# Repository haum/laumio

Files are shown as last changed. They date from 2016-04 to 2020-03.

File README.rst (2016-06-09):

Laumio
######

Setup
=====

You need the Arduino IDE.

Install ESP8266 toolkit for Arduino
-----------------------------------

Instructions here : https://github.com/esp8266/Arduino

Install libraries
-----------------

- https://github.com/adafruit/Adafruit_NeoPixel
- https://github.com/bblanchon/ArduinoJson

Compiling
=========

Open sketch using Arduino
-------------------------

Open the laumio.ino sketch.

Select board
------------

Select the board in the board type to "WeMos D1 R2 & mini".

Flash
-----

You can now compile and flash the sketch to the board.

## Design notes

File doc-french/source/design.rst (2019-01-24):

Conception du Laumio
====================

Le Laumio est constitué d'une `lampe Ikea FADO`_ et d'une structure "maison" contrôlant 13 LEDs RGB.

Cette structure physique est elle-même constituée d'une partie mécanique supportant les lampes et du système électronique associé.

Partie mécanique
----------------

.. tip::

  Tous les fichiers de conception peuvent être récupérés `sur le dépôt Git`_.

La structure mécanique est composée d'un tronc central conçu pour se tenir sur la douille de l'ampoule. Celui-ci a été usiné grâce à une minifraiseuse et assemblé sans colle.

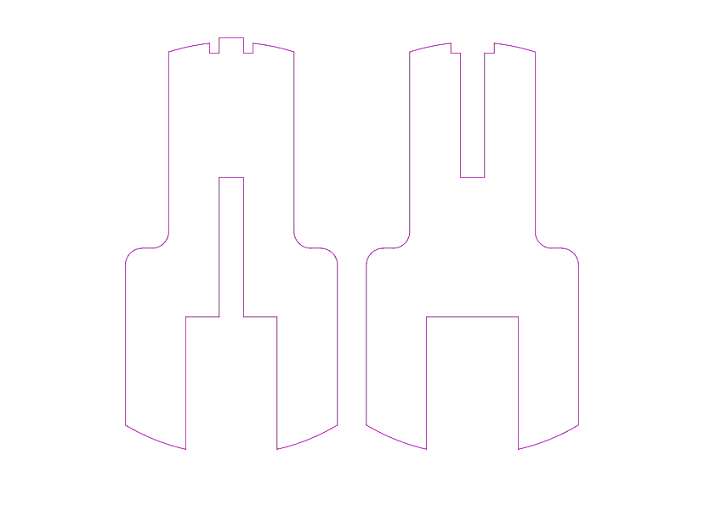
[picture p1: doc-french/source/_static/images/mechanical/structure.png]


Deux propositions ont ensuite été portées pour accueillir les LEDs en elles-mêmes.

La première proposition est basée sur des bras pliables, les LEDs étant collées à leurs extrémités. Les problèmes qui en découlent sont principalement la fragilité de la conception (notamment au niveau des soudures) et l'importante manipulation nécessaire pour insérer cet arbre dans le verre.

La seconde proposition est toujours à l'étude. Celle-ci utiliserait des bandes de plastique souple reliées en haut et en bas de la structure.

Système électronique
--------------------

Le système électronique est construit autour d'un `ESP Wemos d1 Mini`_ de de 13 LED WS2812. Afin de réutiliser le  Wemos dans d'autres projets, il a été décidé de créer un shield adapter pour y connecter le microcontrôleur.
Les fichiers de conception KiCAD design de ce shield peuvent être `téléchargés ici`_.

Le code utilisé dans l'ESP est aussi `présent sur le dépôt`_, merci de lire le fichier `README`_ pour être en mesure de compiler et de flasher le programme.

Une fois flashé et démarré, le Laumio va chercher à se connecter au réseau WiFi spécifié (voir
``wifi-config.h``) et attendre des instructions UDP ou HTTP.

Démarrage
---------

Au lancement, le Laumio clignote en violet puis démarre une animation de couleur rouge : il est en train de chercher le réseau WiFi spécifié et va tenter de s'y connecter.

Si la connexion est réussie, le Laumio lancera une animation Arc-en-ciel. Sinon, il s'illuminera en orage, signalant par-là que le mode *Access Point* est activé. Ce mode permettra à l'utilisateur de donner les informations nécessaires pour connecter l'appareil à un réseau WiFi valide.

.. _lampe Ikea FADO: http://www.ikea.com/us/en/catalog/products/70096377/
.. _ESP Wemos d1 Mini: http://www.wemos.cc/Products/d1_mini.html
.. _sur le dépôt Git: https://github.com/haum/laumio/tree/master/CAD
.. _téléchargés ici: https://github.com/haum/laumio/tree/master/kicad/wemos_d1mini_shield
.. _présent sur le dépôt: https://github.com/haum/laumio/tree/master/laumio
.. _README: https://github.com/haum/laumio/blob/master/README.rst

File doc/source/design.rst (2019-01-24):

Designing the Laumio
====================

Laumio is based on a `Ikea FADO lamp`_ and a homemade system bearing 13 RGB LED.

The physical system itself is composed of the mechanical part supporting the lamps and
the electronic board and system.

Mechanical Part
---------------

.. tip::

  All the design files can be found `on the Git repository`_.

The mechanical part is composed of a central structure designed to stand on the lightbulb
socket. It's is machined using a in-house CNC mill and dry-assembled.



Two different propositions were made to hold the LED themselves.

The first one is based on foldable arms with LED glued at the ends. The main issues are
both the fragility of the design and the effort needed to fit it in the glass.

The second one, still under study, is based on flexible plastic branches cruve from the to
to the bottom of the structure.

Electronic system
-----------------

The electronic system consist of a `ESP Wemos d1 Mini`_ and on 13 LED WS2812. To be able
to reuse the Wemos in other projects, it was decided to create a shield to dock it on. The
KiCAD design files for the shield itself can be `downloaded here`_.

The code running on the ESP is `given on the repo too`_, please follow the `README`_ to be
able to compile and flash it.

Once flashed and started, the Laumio will look for the specified Wifi network (see
``wifi-config.h``) and wait for UDP or HTTP instructions.

Booting
-------

At startup, the Laumio blinks in purple and then starts a red animation : it's looking for
the specified Wifi network and trying to connect.

If the connection is successful, the Laumio will show a rainbow animation, if not, it will
light up in orange, indicating the *Access Point* mode was started. This mode will allow
one to specify the correct information to connect to a Wifi network.

.. _Ikea FADO lamp: http://www.ikea.com/us/en/catalog/products/70096377/
.. _ESP Wemos d1 Mini: http://www.wemos.cc/Products/d1_mini.html
.. _on the Git repository: https://github.com/haum/laumio/tree/master/CAD
.. _downloaded here: https://github.com/haum/laumio/tree/master/kicad/wemos_d1mini_shield
.. _given on the repo too: https://github.com/haum/laumio/tree/master/laumio
.. _README: https://github.com/haum/laumio/blob/master/README.rst

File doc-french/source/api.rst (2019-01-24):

Anatomie du Laumio's et and commandes en valeurs hexadécimales
==============================================================

Le laumio peut être commandé via une API UDP minimale utilisant des commandes
simples en hexadécimal envoyées sur le **port 6969**, via une interface REST ou
à travers MQTT.

Quatre types de sous-ensembles sont utilisables pour commander les LEDs du
Laumio : le pixel (une seule led), l'anneau, la colonne et le Laumio dans son
intégralité. Il est aussi possible de lancer quelques animations plus spécifiques.

Les LEDs sont disposées en 4 branches de trois LEDs, en plus d'une à son sommet.
Celles-ci sont toutes numérotées de 0 à 12 depuis le bas d'une des branches vers
sa cîme, évitant l'unique led du sommet, descendant ensuite de l'autre côté de
la structure, et enfin remontant du bas d'une des deux branches restantes pour
atteindre le bas de la dernière (la LED de sommet étant cette fois-ci reliée
entre les deux branches).

Les anneaux correspondant quant à eux à une ligne horizontale de LEDs. Il y en a
trois numérotées de 0  à 2, de bas en haut.

Enfin, dans le cas des colonnes, celles-ci se rapportent aux quatre branches de
LEDs, bien entendu sans la LED du sommet.

API UDP minimale
----------------

Commande pixel par pixel
************************

La commande est ``0x00``. Les données à envoyer sont d'abord l'ID du pixel considéré et les trois octets de la couleur (RGB) choisie::

  0x00 PixelID R G B

Commande anneau par anneau
**************************

La commande est ``0x01``. Il faut d'abord spécifier l'ID de l'anneau (``0x00``, ``0x01`` or ``0x02``) puis préciser les trois octets de couleur::

  0x01 RingID R G B

Commande colonne par colonne
****************************

La commande est ``0x02``. Ici, il faut indiquer l'ID de la colonne (``0x00``, ``0x01``, ``0x02`` or ``0x03``) puis les trois octets de couleur::

  0x02 ColumnID R G B

Remplissage intégral
********************

La commande est ``0xff``, il suffit ensuite de specifier la couleur RGB::

  0xff R G B

Animations
**********

Les animations prédéfinies sont encore en développement mais deux d'entre elles ont déjà implémentées dans le Laumio.

Remplissage progressif
~~~~~~~~~~~~~~~~~~~~~~

L'animation de Remplissage progressif ("color wipe") change passe le Laumio intégralement dans une seule couleur, mais LED après LED. Elle prend deux paramètres, que sont les trois octets de la nouvelle couleur et l'intervalle de temps entre de deux LEDs en millisecondes::

  0x0b R G B Delay

Arc-en-ciel
~~~~~~~~~~~

L'animation Arc-en-ciel ("rainbow") ne prend pas de paramètres. En l'occurence, c'est celle utilisée par le Laumio quand celui-ci réussit à se connecter à un réseau WiFi::

  0x0a

API REST
--------

L'API REST peut être appelée en envoyant des données sur le chemin ``/api/``.

Statut
******

Le statut du Laumio peut être obtenu en utilisant un endpoint de l'``/api/``::

  GET http://<laumio_ip>/api/

La réponse reçue et de la forme suivante :

.. code-block:: javascript

  {"hostname":"laumio","version":"devel"}

Commandes
*********

Le Laumio peut être controllé à travers un simple requête POST avec une donnée
JSON jointe. Voir l'API JSON pour les détails du contenu de ces JSON.

En cas de succès :

.. code-block:: javascript

  {"hostname":"laumio","status":"Success"}

En cas d'erreur :

.. code-block:: javascript

  {"hostname":"laumio","status":"Invalid Request","massage":"Unable to parse JSON"}

API MQTT
--------

Si le Laumio a pu se connecter au broker, il peut être contrôlé à travers MQTT.

Status de connexion
********************

A la connexion le laumio publie sur le topic ``laumio/<name>/status`` son status de connexion,
Si le laumio se trouve hors ligne ce topic publiera un status offline

Annonce
*******

À la connexion, il publie son nom sur le topic ``laumio/status/advertise``.

Ce même message est envoyé quand il reçoit une commande ``discover``.

Commandes
*********

La commande est choisie en fonction du topic : ``laumio/all/<cmd>`` ou ``laumio/<name>/<cmd>``
selon que vous voulez l'envoyer à tous les clients connectés ou à un en particulier.

set_pixel
~~~~~~~~~

Change la couleur d'une led.

Les 4 octets du message sont le numéro de la led suivi des composantes rouge, vert, bleu de la couleur (0 à 255)

set_ring
~~~~~~~~~

Change la couleur d'un anneau.

Les 4 octets du message sont le numéro de l'anneau suivi des composantes rouge, vert, bleu de la couleur (0 à 255)

set_column
~~~~~~~~~~

Change la couleur d'une colonne.

Les 4 octets du message sont le numéro de la colonne suivi des composantes rouge, vert, bleu de la couleur (0 à 255)

color_wipe
~~~~~~~~~~

Démarre l'animation de remplissage progressif avec une couleur et une durée.

Les 4 octets du message sont les composantes rouge, vert, bleu de la couleur (0 à 255) suivies de la durée.

animate_rainbow
~~~~~~~~~~~~~~~

Démarre l'animation arc-en-ciel.

Le contenu du message est ignoré.

fill
~~~~

Change la couleur de toutes les leds.

Les 3 octets du message sont les composantes rouge, vert, bleu de la couleur (0 à 255)

json
~~~~

Envoie des commandes JSON via l'API JSON.

discover
~~~~~~~~

Renvoie un message sur le topic ``laumio/status/advertise`` contenant son nom.

API JSON
--------

Cette API ne peut pas être utilisée seule. Elle est accédée soit par la commande
``json`` de l'interface MQTT ou par l'API REST.

Commandes
*********

set_pixel
~~~~~~~~~

Change la couleur d'une led.

.. code-block:: javascript

  {
    'command': 'set_pixel',
    'led': PixelID,
    'rgb': [R, G, B]
  }

set_ring
~~~~~~~~~

Change la couleur d'un anneau.

.. code-block:: javascript

  {
    'command': 'set_ring',
    'ring': RingID,
    'rgb': [R, G, B]
  }

set_column
~~~~~~~~~~

Change la couleur d'une colonne.

.. code-block:: javascript

  {
    'command': 'set_column',
    'column': ColumnID,
    'rgb': [R, G, B]
  }

color_wipe
~~~~~~~~~~

Démarre l'animation de remplissage progressif avec une couleur et une durée.

.. code-block:: javascript

  {
    'command': 'color_wipe',
    'duration': Duration,
    'rgb': [R, G, B]
  }

animate_rainbow
~~~~~~~~~~~~~~~

Démarre l'animation arc-en-ciel.

.. code-block:: javascript

  {
    'command': 'animate_rainbow',
  }

fill
~~~~

Change la couleur de toutes les leds.

.. code-block:: javascript

  {
    'command': 'fill',
    'rgb': [R, G, B]
  }

Commandes multiples
*******************

Quelques commandes peuvent être chaînées dans un même appel lorsqu'elles
sont regroupées dans un tableau nommé ``commands``, mais notez que la
taille du JSON est quelque peu limitée.

.. code-block:: javascript

  {
    'commands': [
      {
        'command': 'set_column',
        'column': 0,
        'rgb': [255, 0, 0]
      },
      {
        'command': 'set_column',
        'column': 2,
        'rgb': [0, 0, 255]
      }
    ]
  }

Commande pixel par pixel (ancienne API)
***************************************

.. code-block:: javascript

  {
    'led': PixelID,
    'rgb': [R, G, B]
  }

Remplissage intégral (ancienne API)
***********************************

.. code-block:: javascript

  {
    'led': 255,
    'rgb': [R, G, B]
  }

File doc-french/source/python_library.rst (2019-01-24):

Librairie Python
================

La classe ``Laumio`` est construite comme une encapsulation des commandes minimales présentées dans la `page de l'API`_.

.. py:class:: Laumio

  .. py:method:: __init__(ip)

    Constructeur pour contrôler un Laumio répondant à l'adresse IP *ip*.

  .. py:method:: wipeOut()

    Eteint toutes les LEDs.

    *En réalité juste un alias pour :py:method:`fillColor`*.

  .. py:method:: fillColor(r, g, b)

    Remplit toutes les LEDs du Laumio avec la couleur (*r*, *g*, *b*).

  .. py:method:: fillRing(ringid, r, g, b)

    Remplit un anneau d'une seule couleur. *ringid* est dans l'intervalle 0~3 et *r*, *g*, *b* précisent la couleur.
    La LED du sommet n'est pas commandable ici.

  .. py:method:: fillColumn(colmunid, r, g, b)

    Remplit une colonne d'une seule couleur. *columnid* est dans l'intervalle 0~4 et *r*, *g*, *b* précisentla couleur.
    La LED du sommet n'est pas incluse dans les colonnes.

  .. py:method:: setPixelColor(pixel, r, g, b)

    Passe un pixel *pixel* (0~12) à la couleur (*r*, *g*, *b*) demandée.

  .. py:method:: colorWipe(r, g, b, delay)

    Lance une animation de remplissage progressif avec la color (*r*, *g*, *b*) et un intervalle de temps *delay* entre deux LEDs.

  .. py:method:: rainbow()

    Lance une animation arc-en-ciel.

  .. py:method:: status()

    Return the JSON **string** for the Laumio's status

  .. py:method:: _send(payload)

    Conventionnaly private, this method is used to transmit a raw ``bytearray`` payload to
    a Laumio. It can be used to trigger custom animations.

.. _page de l'API: /api.html

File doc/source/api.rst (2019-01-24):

Laumio's anatomy and HEX commands
=================================

The Laumio can be controlled using the bare-UDP API using simple HEX commands sent on the
**port 6969**, using REST API or through MQTT.

Four different features can be set : the pixel, ring, column and the whole Laumio at once.
Additionnaly, some animations can be triggered.

The leds are disposed in 4 branches of three LED plus one at the top. They are numbered
starting from the bottom of one branch to its top, skipping the led at the center, going
down on the other side and then from the bottom of one of the other two branches to the
bottom of the other (with the top middle LED included).

The so-called rings correspond to a layer of LED. There's three of them, numbered from
bottom to top.

As for the columns, they correspond to the four branches of LEDs, of course without the top LED.

Bare UDP
--------

Pixel-wise control
******************

The command is ``0x00`` and the data to be sent is first the pixel ID and the three byte
of the (RGB) color::

  0x00 PixelID R G B

Ring-wise control
*****************

The command is ``0x01`` and one must specify first the ring (``0x00``, ``0x01`` or ``0x02``) and
then the three bytes of the color::

  0x01 RingID R G B

Column-wise control
*******************

The command is ``0x02`` and one must specify first the column (``0x00``, ``0x01``, ``0x02`` or ``0x03``) and
then the three bytes of the color::

  0x02 ColumnID R G B

Full span control
*****************

The command is ``0xff`` and the only thing to specify is the RGB color::

  0xff R G B

Animations
**********

This is still a work in progress but 2 animations can be triggered on the Laumio.

Color Wipe
~~~~~~~~~~

The color wipe animation changes the color on the full Laumio one LED at a time. It takes
two parameters, the 3 bytes of color and the delay (ms between each light-up) between two LED::

  0x0b R G B Delay

Rainbow
~~~~~~~

The rainbow animation takes no parameters, it's the one used when the Laumio manage to
connect to a Wifi network::

  0x0a

REST API
--------

The REST API can be called by sending JSON data to the ``/api/`` endpoint.

Status
******

The status of the Laumio can be retrieved using a simple ``GET`` request, no data requiered::

  GET http://<laumio_ip>/api/

The response is given in the form :

.. code-block:: javascript

  {"hostname":"laumio","version":"devel"}

Commands
********

The Laumio can be controlled through simple POST requests with JSON content. See
JSON API for details about JSON content to send.

In case of success:

.. code-block:: javascript

  {"hostname":"laumio","status":"Success"}

In case of failure:

.. code-block:: javascript

  {"hostname":"laumio","status":"Invalid Request","massage":"Unable to parse JSON"}

MQTT API
--------

If the laumio can connect to your broker, it can be controlled through MQTT.

Online status
*************

At connection laumio publishes to the topic ``laumio/<name>/status`` is online status,
if laumio will go offline this topic will send an offline status

Advertise
*********

At connection, it publishes its name to the topic ``laumio/status/advertise``.

The same message is sent when it receives a ``discover`` command.

Commands
********

The command is chosen with the topic: ``laumio/all/<cmd>`` or ``laumio/<name>/<cmd>``
whether you want to send it to all connected clients or to a specific one.

set_pixel
~~~~~~~~~

Change color of a led.

The 4 bytes payload is the led number followed by red, green, blue components of the color (0-255 range)

set_ring
~~~~~~~~~

Change color of a ring.

The 4 bytes payload is the ring number followed by red, green, blue components of the color (0-255 range)

set_column
~~~~~~~~~~

Change color of a column.

The 4 bytes payload is the column number followed by red, green, blue components of the color (0-255 range).

color_wipe
~~~~~~~~~~

Start color wipe animation with a given color and duration.

The 4 bytes payload is red, green, blue components of the color (0-255 range) followed by duration.

animate_rainbow
~~~~~~~~~~~~~~~

Start rainbow animation.

Payload is ignored.

fill
~~~~

Set the same color for all leds.

The 3 bytes payload is red, green, blue components of the color (0-255 range).

json
~~~~

Send JSON commands through the JSON API.

discover
~~~~~~~~

Send back a ``laumio/status/advertise`` message with its name as payload.

JSON API
--------

This API cannot be used alone. It is accessed either though MQTT ``json`` command or REST API.

Commands
********

set_pixel
~~~~~~~~~

Change color of a led.

.. code-block:: javascript

  {
    'command': 'set_pixel',
    'led': PixelID,
    'rgb': [R, G, B]
  }

set_ring
~~~~~~~~~

Change color of a ring.

.. code-block:: javascript

  {
    'command': 'set_ring',
    'ring': RingID,
    'rgb': [R, G, B]
  }

set_column
~~~~~~~~~~

Change color of a column.

.. code-block:: javascript

  {
    'command': 'set_column',
    'column': ColumnID,
    'rgb': [R, G, B]
  }

color_wipe
~~~~~~~~~~

Start color wipe animation with a given color and duration.

.. code-block:: javascript

  {
    'command': 'color_wipe',
    'duration': Duration,
    'rgb': [R, G, B]
  }

animate_rainbow
~~~~~~~~~~~~~~~

Start rainbow animation.

.. code-block:: javascript

  {
    'command': 'animate_rainbow',
  }

fill
~~~~

Set the same color for all leds.

.. code-block:: javascript

  {
    'command': 'fill',
    'rgb': [R, G, B]
  }

Multiple commands
*****************

A few commands can be chained in one call when set in the same array named
``commands``, but beware that the size of JSON is somewhat limited.

.. code-block:: javascript

  {
    'commands': [
      {
        'command': 'set_column',
        'column': 0,
        'rgb': [255, 0, 0]
      },
      {
        'command': 'set_column',
        'column': 2,
        'rgb': [0, 0, 255]
      }
    ]
  }

Pixel-wise control (legacy API)
*******************************

.. code-block:: javascript

  {
    'led': PixelID,
    'rgb': [R, G, B]
  }

Full span control (legacy API)
******************************

.. code-block:: javascript

  {
    'led': 255,
    'rgb': [R, G, B]
  }

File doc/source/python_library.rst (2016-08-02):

Python Library
==============

The class ``Laumio`` is built as a wrapper around the primitives exposed in the `API
page`_.

.. py:class:: Laumio

  .. py:method:: __init__(ip)

    Constructor to control a Laumio responding on IP address *ip*.

  .. py:method:: wipeOut()

    Shuts down all the LED

    *Actually just an alias for :py:method:`fillColor`*.

  .. py:method:: fillColor(r, g, b)

    Fill the whole Laumio with a color (*r*, *g*, *b*).

  .. py:method:: fillRing(ringid, r, g, b)

    Fill a ring with a color. *ringid* can be 0~3 and *r*, *g*, *b* specify the color.
    The top LED is not addressed.

  .. py:method:: fillColumn(colmunid, r, g, b)

    Fill a column with a color. *columnid* can be 0~4 and *r*, *g*, *b* specify the color.
    The top LED is not addressed.

  .. py:method:: setPixelColor(pixel, r, g, b)

    Set a pixel *pixel*  (0~12) to a given color (*r*, *g*, *b*).

  .. py:method:: colorWipe(r, g, b, delay)

    Start a color wipe animation with color (*r*, *g*, *b*) and inter-LED delay *delay*.

  .. py:method:: rainbow()

    Start a rainbow animation.

  .. py:method:: status()

    Return the JSON **string** for the Laumio's status

  .. py:method:: _send(payload)

    Conventionnaly private, this method is used to transmit a raw ``bytearray`` payload to
    a Laumio. It can be used to trigger custom animations.

.. _API page: /api.html

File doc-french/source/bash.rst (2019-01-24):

Interface bash minimale
=======================

Le Laumio peut être commandé très simplement en utilisant `socat`_ ou n'importe quel autre outil réseau bien conçu.

Nous vous proposons le code suivant en guise d'exemple et de base de travail :

.. code-block:: bash

  #!/bin/bash

  # Consts
  IP=             # Laumio's IP
  ANIM_TIME=0.05
  PAUSE_TIME=0.3

  # Utils
  fill() {
    echo -en "\xff\x$1\x$2\x$3"
  }

  led() {
    echo -en "\x00\x$1\x$2\x$3\x$4"
  }

  ring() {
    echo -en "\x01\x$1\x$2\x$3\x$4"
  }

  column() {
    echo -en "\x02\x$1\x$2\x$3\x$4"
  }

  # Program
  (
  fill 00 00 00
  sleep $ANIM_TIME

  while true; do

    # write your animation here...

  done
  ) | socat - udp-sendto:$IP:6969

En outre, il est également possible d'envoyer plusieurs commandes en une seule requête, comme dans l'exemple suivant:

.. bash::  echo -en "\xff\xFF\x00\x00\x00\x09\xff\xff\xff" | socat - udp-sendto:$IP:6969

Ici, le Laumio est d'abord intégralement passé en rouge, puis la LED du sommet est passée en blanc.

.. _socat: http://www.dest-unreach.org/socat/

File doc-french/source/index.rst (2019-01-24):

Doc de Laumio : une lampe connectée programmable
==================================================

Un Laumio est une  `lampe Ikea`_ bidouillée par le HAUM_ et incluant 13 LEDs RGB. Celui-ci peut être programmé directement en  Wifi via ``socat``, l'interprêteur Python or en... regardant l'API.

Tout le code est disponible sur le `dépôt Github`_ dédié. Vous êtes libres de l'utilier, de le cloner, de le modifier, et de le publier.

Une version anglaise de la documentation est aussi disponible ici_.

.. toctree::
   :maxdepth: 2

   design
   api
   bash
   python_library

.. _lampe Ikea: http://www.ikea.com/us/en/catalog/products/70096377/
.. _HAUM: https://haum.org
.. _dépôt Github: https://github.com/haum/laumio
.. _ici: https://laumio.readthedocs.io/en/latest

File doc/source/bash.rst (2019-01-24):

Simple Bash Interface
=====================

The Laumio can be controlled simply using `socat`_ or any other well-designed network tool.

One can use the following boilerplate :

.. code-block:: bash

  #!/bin/bash

  # Consts
  IP=             # Laumio's IP
  ANIM_TIME=0.05
  PAUSE_TIME=0.3

  # Utils
  fill() {
    echo -en "\xff\x$1\x$2\x$3"
  }

  led() {
    echo -en "\x00\x$1\x$2\x$3\x$4"
  }

  ring() {
    echo -en "\x01\x$1\x$2\x$3\x$4"
  }

  column() {
    echo -en "\x02\x$1\x$2\x$3\x$4"
  }

  # Program
  (
  fill 00 00 00
  sleep $ANIM_TIME

  while true; do

    # write your animation here...

  done
  ) | socat - udp-sendto:$IP:6969

You can also send various commands in one request as in the following example:

.. bash:: echo -en "\xff\xFF\x00\x00\x00\x09\xff\xff\xff" | socat - udp-sendto:$IP:6969

In this command, the Laumio is entirely red colored; then the top LED is set to white color.

.. _socat: http://www.dest-unreach.org/socat/

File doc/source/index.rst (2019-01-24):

Laumio's doc : a network programmable lamp
==========================================

Laumio is a hacked `Ikea lamp`_ from the HAUM_ with 13 RGB LED included. It can be programmed over Wifi
directly using ``socat``, the Python wrapper or by... looking at the API.

All the code is available on the dedicated `Github repo`_. Feel free to use it, clone it
hack it, release it.

A french version of this documentation is also available here_.

.. toctree::
   :maxdepth: 2

   design
   api
   bash
   python_library

.. _Ikea lamp: http://www.ikea.com/us/en/catalog/products/70096377/
.. _HAUM: https://haum.org
.. _github repo: https://github.com/haum/laumio
.. _here: https://laumio.readthedocs.io/fr/latest

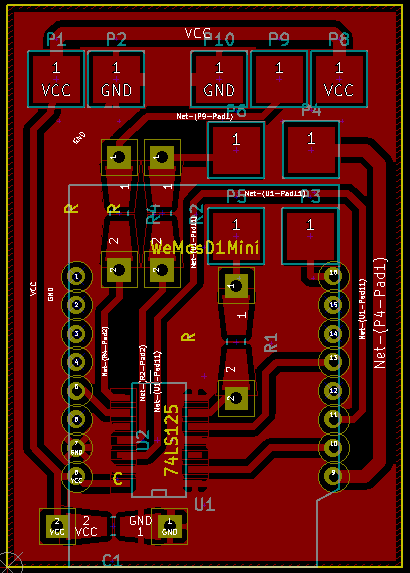
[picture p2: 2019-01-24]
kicad/wemos_d1mini_shield/wemos_d1mini_shield.png

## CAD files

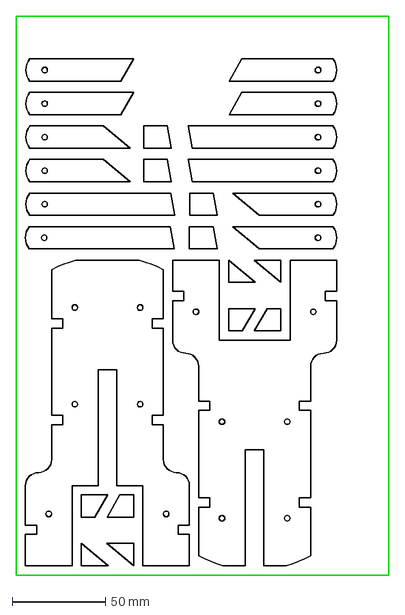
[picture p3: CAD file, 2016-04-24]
CAD/CAM/fado-mod-cam.dxf
200.0 x 300.0 mm

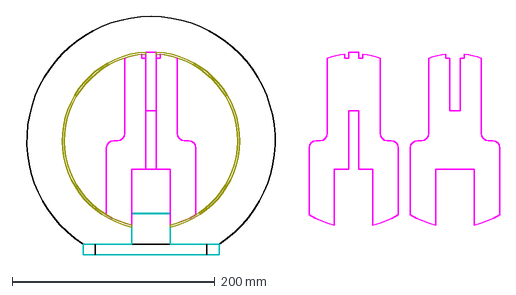
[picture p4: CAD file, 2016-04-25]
CAD/fado-mod.dxf
476.9 x 235.0 mm

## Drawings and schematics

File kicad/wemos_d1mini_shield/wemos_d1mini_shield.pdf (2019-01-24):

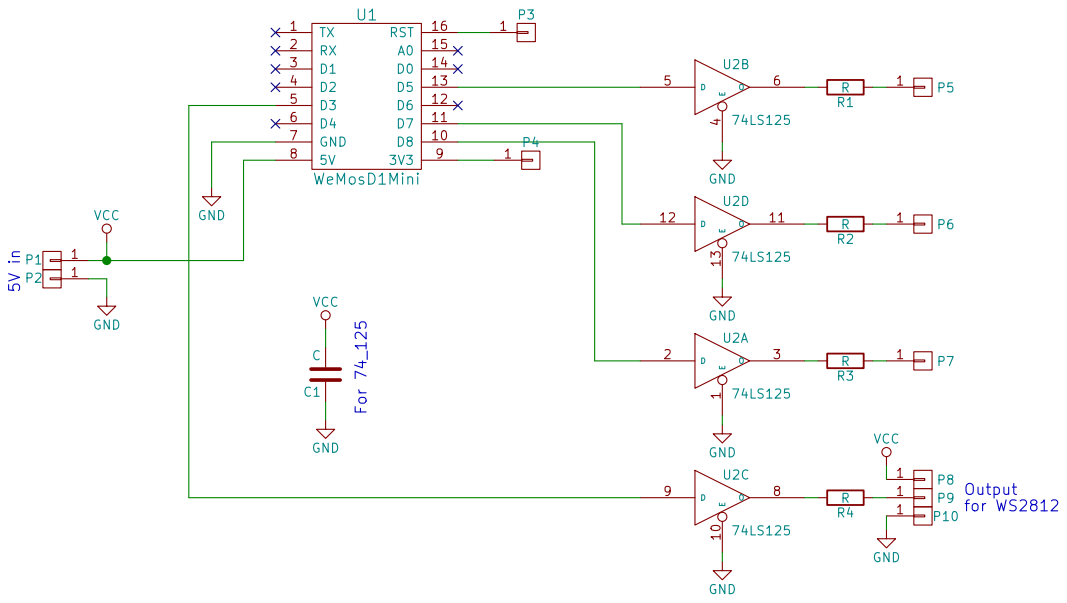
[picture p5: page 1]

File: wemos_d1mini_shield.sch Sheet: / HAUM - Hackerspace AU Mans

Id: 1/1 Title: WeMosD1Mini shield for Laumio

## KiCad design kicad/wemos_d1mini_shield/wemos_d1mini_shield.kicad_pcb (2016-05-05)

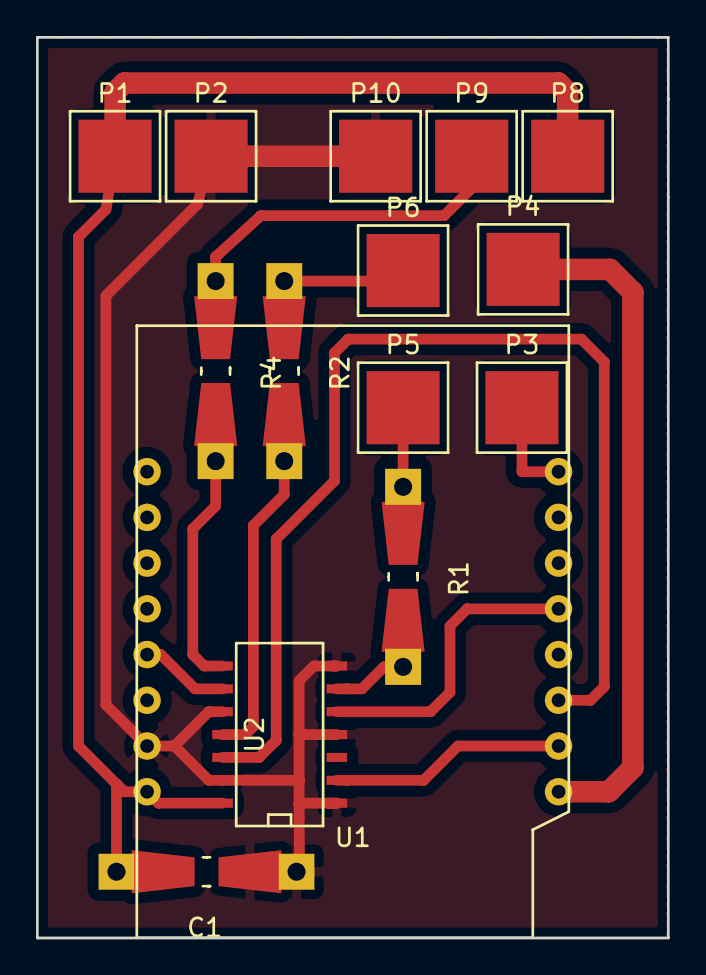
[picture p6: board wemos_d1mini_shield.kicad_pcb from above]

Board: 2 copper layers, 35.1 x 50.0 mm, 15 parts (0 on the bottom side), 14 nets.

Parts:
C1: C; Resistor_SMD+THTuniversal_0805to1206_RM10_HandSoldering
P1, P2, P3, P4, P5, P6, P8, P9, P10: 1Pin
R1, R2, R4: R; Resistor_SMD+THTuniversal_0805to1206_RM10_HandSoldering
U1: WeMosD1Mini
U2: 74LS125; SOIC-14_N

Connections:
GND: C1.1, P2.1, P10.1, U1.7, U2.1, U2.4, U2.7, U2.10, U2.13
unnamed: P3.1, U1.16
unnamed: P4.1, U1.9
unnamed: P5.1, R1.1
unnamed: P6.1, R2.1
unnamed: P9.1, R4.1
unnamed: R1.2, U2.6
unnamed: R2.2, U2.11
unnamed: R4.2, U2.8
unnamed: U1.5, U2.9
unnamed: U1.10, U2.2
unnamed: U1.11, U2.12
unnamed: U1.13, U2.5
VCC: C1.2, P1.1, P8.1, U1.8, U2.14

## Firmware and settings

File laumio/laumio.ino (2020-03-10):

/*
 * Connections:
 * D3 --- DIN
 * G ---- GND (either)
 *
 * Adafruit recommendations:
 * - add a 1000uF capacitor across the power lines 5VDC and GND.
 * - add a 300-500 Ohm resistor on first pixel's data input DIN.
 * - avoid connecting on a live circuit... if you must, connect GND first.
 *
 * Dependencies:
 * https://github.com/adafruit/Adafruit_NeoPixel
 * https://github.com/bblanchon/ArduinoJson
 */

// Si ancienne version
//#define DIN_PIN D4
#define DIN_PIN D3

#define NUM_PIXELS 13

/* Old versions of Arduino pseudo-IDE need these to compile the code **/
#include <Adafruit_NeoPixel.h>
#include <ArduinoJson.h>
#include <ArduinoOTA.h>
#include <DNSServer.h>
#include <EEPROM.h>
#include <ESP8266WebServer.h>
#include <ESP8266WiFi.h>
#include <ESP8266mDNS.h>
#include <WiFiUdp.h>
/* Perhaps other later */

#include "LaumioConfig.h"
#include "LaumioHttp.h"
#include "LaumioHttpApi.h"
#include "LaumioHttpConfig.h"
#include "LaumioLeds.h"
#include "LaumioMQTT.h"
#include "LaumioUdpRemoteControl.h"
#include "ota_helpers.h"

LaumioLeds leds(NUM_PIXELS, DIN_PIN);
LaumioConfig config;

ESP8266WebServer webserver(80);
LaumioHttp http_handler(config, webserver);
LaumioHttpApi http_api_handler(leds, webserver);
LaumioHttpConfig http_config_path(config, webserver);

DNSServer dns;

LaumioUdpRemoteControl udpRC(leds);
LaumioMQTT mqtt_client(leds, config);

bool connect_enabled;
bool ap_enabled;
bool apfallback_enabled;
bool mqtt_enabled;

void setup() {
	Serial.begin(115200);
	Serial.println("Starting Laumio\n");

	config.readFromEEPROM();
	if (!strcmp(config.hostname, "")) {
		char hostString[14];
		sprintf(hostString, "Laumio_%06X", ESP.getChipId());
		config.hostname.setValue(hostString);
	}

	connect_enabled = config.connect_enabled;
	ap_enabled = config.ap_enabled;
	apfallback_enabled = config.apfallback_enabled;
	mqtt_enabled = config.mqtt_enabled;

	Serial.print("Hostname: ");
	Serial.println(config.hostname);

	leds.begin();
	leds.animate(LaumioLeds::Animation::Clear);
	leds.animate(LaumioLeds::Animation::Hello);


	webserver.begin();
	WiFi.hostname(config.hostname);
	if (MDNS.begin(config.hostname)){
		MDNS.addService("http", "tcp", 80);
    }
	ota_setup(config.hostname);

	Serial.print("Connection to wifi");
	if (config.connect_enabled && strcmp(config.connect_essid, "")) {
		Serial.print(": \"");
		Serial.print(config.connect_essid);
		Serial.println('"');
		WiFi.begin(config.connect_essid, config.connect_password);
	} else {
		Serial.println(" disabled");
	}

	Serial.print("Wifi access point");
	if (config.ap_enabled && strcmp(config.ap_essid, "")) {
		Serial.print(": \"");
		Serial.print(config.ap_essid);
		Serial.print('"');
		if (WiFi.softAP(config.ap_essid, config.ap_password)) {
			Serial.print(' ');
			Serial.println(WiFi.softAPIP());
			dns.start(53, "*", WiFi.softAPIP());
		} else {
			Serial.println(" failed");
			ap_enabled = false;
		}
	} else {
		WiFi.softAPdisconnect();
		Serial.println(" disabled");
	}

	if (mqtt_enabled)
		mqtt_client.begin();
	udpRC.begin();
	MDNS.begin(config.hostname.value());
  /**/
}

void loop() {
	ota_loop();
	dns.processNextRequest();
	webserver.handleClient();
	udpRC.handleMessage();
	if (mqtt_enabled)
		mqtt_client.loop();

	// Connection indicator
	static bool connectionFailed = false;
	if (connect_enabled && !connectionFailed) {
		static int connectCounter = 0;
		if (WiFi.status() != WL_CONNECTED) {
			if (connectCounter == 10) {
				leds.colorWipe(0xff3c00, 100);
				connectCounter++;
				WiFi.disconnect();
				Serial.println("Connection failed (too long)");
				connectionFailed = true;
			} else {
				leds.animate(LaumioLeds::Animation::Loading);
				connectCounter++;
			}
		} else if (connectCounter != -1) {
			Serial.print("Wifi connected: ");
			Serial.println(WiFi.localIP());
			leds.animate(LaumioLeds::Animation::Happy);
			leds.animate(LaumioLeds::Animation::Clear);
			connectCounter = -1;
		}
	} else {
		connectionFailed = true;
	}

	// Fallback
	if (connectionFailed && !ap_enabled) {
		if (apfallback_enabled) {
			Serial.print("Access point fallback enabled: \"");
			Serial.print(config.hostname);
			Serial.print('"');

			if (WiFi.softAP(config.hostname, "")) {
				Serial.print(' ');
				Serial.println(WiFi.softAPIP());
				dns.start(53, "*", WiFi.softAPIP());
				ap_enabled = true;
			} else {
				Serial.println(" failed");
				delay(3000);
				ESP.restart();
			}
		} else {
			delay(3000);
			ESP.restart();
		}
	}
}

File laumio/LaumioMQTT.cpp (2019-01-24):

#include "LaumioMQTT.h"

namespace { // All in this namespace is soup to make the lib call a
	        // member-function instead of global-space-function
LaumioMQTT *mqtt = nullptr;
void mqtt_callback(char *topic, byte *payload, unsigned int length) {
	if (mqtt)
		mqtt->callback(topic, payload, length);
}
} // namespace

LaumioMQTT::LaumioMQTT(LaumioLeds &l, LaumioConfig &c) : leds(l), config(c) {
	mqtt = this;
}

void LaumioMQTT::begin() {
	client.setServer(config.mqtt_host.value(), 1883);
	client.setCallback(mqtt_callback);
	strncpy(topicId, config.hostname.value(), sizeof(topicId));
}

void LaumioMQTT::loop() {
	if (!client.connected()) {
		long now = millis();
		if (now - lastReconnectAttemptDate > 10 * 1000) {
			lastReconnectAttemptDate = now;

			// Attempt to reconnect
			Serial.print("Attempting MQTT connection...");
			char laumioLastWillTopic[14 + 13];
			sprintf(laumioLastWillTopic, "laumio/status/%13s", topicId);
			if (client.connect(topicId, config.mqtt_user.value(),
			                   config.mqtt_password.value(),
			                   laumioLastWillTopic, 0, 1, "offline")) {
				Serial.println(" connected.");

				// Once connected, publish an announcement...
				client.publish(laumioLastWillTopic, "online", true);
				client.publish("laumio/status/advertise", topicId);

				// ... and resubscribe
				client.subscribe("laumio/all/#");
				char myTopicsWildcard[10 + 13];
				sprintf(myTopicsWildcard, "laumio/%13s/#", topicId);
				client.subscribe(myTopicsWildcard);

			} else {
				Serial.print(" failed. (state=");
				Serial.print(client.state());
				Serial.println(")");
			}

			if (client.connected()) {
				lastReconnectAttemptDate = 0;
			}
		}

	} else {
		// Client connected
		client.loop();
	}
}

void LaumioMQTT::callback(char *topic, byte *payload, unsigned int len) {
	// Display topic and payload
	Serial.print("[MQTT topic] ");
	Serial.print(topic);
	Serial.print(" : ");
	for (int i = 0; i < len; i++) {
		Serial.print((char)payload[i], HEX);
		Serial.print(' ');
	}
	Serial.println();

	// Extract command from topic name
	char *cmd = "";
	if (!strncmp(topic, "laumio/all/", 11)) {
		cmd = topic + 11;
	} else {
		char myTopicsStartWith[9 + 13];
		sprintf(myTopicsStartWith, "laumio/%13s/", topicId);
		if (!strncmp(topic, myTopicsStartWith, 8 + 13)) {
			cmd = topic + 8 + 13;
		}
	}

	// Execute command
	if (!strcmp("", cmd)) {
		// No command, or not for me, ignore

	} else if (!strcmp("set_pixel", cmd)) {
		if (len >= 4) {
			leds.setPixelColor(payload[0], payload[1], payload[2], payload[3]);
			leds.show();
		}

	} else if (!strcmp("set_ring", cmd)) {
		if (len >= 4) {
			leds.setRingColor(payload[0], payload[1], payload[2], payload[3]);
			leds.show();
		}

	} else if (!strcmp("set_column", cmd)) {
		if (len >= 4) {
			leds.setColumnColor(payload[0], payload[1], payload[2], payload[3]);
			leds.show();
		}

	} else if (!strcmp("color_wipe", cmd)) {
		if (len >= 4)
			leds.colorWipe(payload[0] << 16 | payload[1] << 8 | payload[2],
			               payload[3]);

	} else if (!strcmp("animate_rainbow", cmd)) {
		leds.rainbowCycle(1);

	} else if (!strcmp("fill", cmd)) {
		if (len >= 3) {
			leds.fillColor(payload[0], payload[1], payload[2]);
			leds.show();
		}

	} else if (!strcmp("json", cmd)) {
		char payload_cstr[len + 1];
		memcpy(payload_cstr, payload, len);
		payload_cstr[len + 1] = 0;
		leds.jsonCommands(payload_cstr);

	} else if (!strcmp("discover", cmd)) {
		client.publish("laumio/status/advertise", topicId);

	} else {
		Serial.print("Command not found: ");
		Serial.println(cmd);
	}
}

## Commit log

2016-04-15 Import tiny code that support our hw setup (LEDs and MCU)
2016-04-16 Put LEDs related things into dedicated class
2016-04-17 Implement minimal API to set led(s)
2016-04-19 LaumioLeds already check if LED index is valid
2016-04-24 Import Fado mod from LHAUMpions repository
    [fado-mod.dxf]
2016-04-24 Import CAM files based on CAD for Fado mod from LHAUMpions repository
    [fado-mod-cam.dxf]
2016-04-24 Import CAD files for Fado mod, reworked by Jblb
    [fado-mod.dxf]
2016-04-24 Import CAM files for Fado mod, reworked by Jblb
    [fado-mod-cam.dxf]
2016-04-24 CAD: cleanup file and remove old layers
    [fado-mod.dxf]
2016-04-24 CAD: try a new design with less parts
    [fado-mod.dxf]
2016-04-25 CAD: ensure its possible to enter into sphere
    [fado-mod.dxf]
2016-04-25 CAD: draw two main parts
    [fado-mod.dxf]
2016-04-29 kicad: add wemosd1mini part
2016-04-29 kicad: add schematic for wemos_d1mini_shield
    [wemos_d1mini_shield.sch]
2016-04-29 kicad: associate components
    [wemos_d1mini_shield.sch]
2016-04-29 kicad: add WeMosD1Mini footprint
2016-04-29 kicad: add project (oups)
2016-04-29 kicad: add null routage
    [wemos_d1mini_shield.kicad_pcb]
2016-04-29 kicad: simplify schematic and begin of routage (WIP)
    [wemos_d1mini_shield.kicad_pcb, wemos_d1mini_shield.sch]
2016-05-05 Use D3 on Wemos D1 mini
    This prevents from having the onboard blue led on (D4)
    [laumio.ino]
2016-05-05 Update PCB design
    This design is working and have been used for "BienVenus sur Venus".
    [wemos_d1mini_shield.kicad_pcb]
2016-05-05 Add 8 Wemos D1 mini shield PCBs panelized 4x2
    [wemos_d1mini_shield__panel.kicad_pcb]
2016-06-18 Added Ring mapping, reworked UDP parsing
    [laumio.ino]
2016-06-18 Fix from last session
    [laumio.ino]
2016-08-06 add inclusions to compile with Arduino 1.6.5 version
2016-08-18 modification du script bash - ajout du paramètre -n sur la commande echo
2016-08-18 modification de la documentation
2016-08-30 Removing AP Mode in case of not found AP, delay and restart instead
2017-02-09 add schematic in pdf
2019-01-08 rework serial output of MQTT handler
    [LaumioMQTT.cpp]
2019-01-08 fix syntax error in previous commit
    [LaumioMQTT.cpp]
2019-01-08 simplify LaumioHttpApi with json interpreter from leds
2019-01-08 fix topic matching conditionals to stop comparison before the trailing command
    [LaumioMQTT.cpp]
2019-01-08 set the number of pixels to the correct number for standard laumios
    [laumio.ino]
2019-01-11 ajout d'un status de connection MQTT
2019-01-11 typo et armonisation des nomages
2019-01-19 fix MQTT binary commands
    [LaumioMQTT.cpp]
2019-01-24 Replace *-config.h by LaumioConfig
    [LaumioMQTT.cpp, laumio.ino]
2020-03-09 change need by upgrade ArduinoJSON library
